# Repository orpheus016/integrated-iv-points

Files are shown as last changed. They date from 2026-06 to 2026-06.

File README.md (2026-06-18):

# four-point-probe
Four point probe for semiconductor instrumentation system

## Software: voltage simulation pipeline

This repo includes a modular Python simulation for voltage acquisition with
filters, live plotting, and CSV logging. It is designed to be swapped later with
ADS1256 serial input from Arduino.

## Development

If you plan to change code, start with:

- [CONTRIBUTING.md](CONTRIBUTING.md) for the CI contract, local preflight, and PR checklist.
- [software/scripts/README.md](software/scripts/README.md) for `evaluate`, `integrate`, and the compliance checker.
- [software/README.md](software/README.md) for the software module overview and run examples.
- `CONTRIBUTING.md` also explains how to write new tests under `software/tests/` and run them from the repo root.

### Setup

Install dependencies:

```bash
pip install matplotlib
```

Optional (for future ADS1256 serial input):

```bash
pip install pyserial
```

### Run

From the repo root:

```bash
python -m software.main
```

Example with custom settings:

```bash
python -m software.main --sample-rate 100 --window-seconds 8 --noise 0.0005 --step
```

## Offline data paths

There are two ways to work with recorded CSV data:

1. Replay a CSV through the live runtime when you want the same pipeline as hardware, including the backbone, logger, and visualizer:

```bash
python -m software.main --source csv --csv-path software/output/testbench/stable20mA.csv --backbone baseline
```

2. Run offline evaluation when you want metrics and snapshot comparison without hardware commands or the live plot loop:

```bash
python -m software.scripts.evaluate --input software/output/testbench/stable20mA.csv --backbones baseline --out software/output/evaluate/baseline-stable20mA
```

The offline evaluator writes a metrics CSV with the decided snapshot fields, marks that chosen snapshot with a star in the plot, and keeps the result separate from the live runtime output.

The default snapshot recording gate is configured in [software/config/config.py](software/config/config.py), including the minimum recording duration used before a backbone may decide on a VI snapshot.

## Serial protocol and CLI

Hardware integration uses a small text protocol implemented by the Arduino firmware and
managed by `software/command/serial_commander.py`.

Framing markers (exact strings):

- `*STREAM_START` — emitted by the Arduino to mark stream beginning
- `*STREAM_STOP` — emitted by the Arduino to mark stream termination

Control commands sent from host to Arduino (single ASCII characters):

- `R` — reset device
- `C` — start streaming samples
- `s` — stop streaming
- `iN` — set current stage to `N` (e.g. `i2`)

The serial reader expects CSV-style measurement lines containing `voltage,current_mA`.

Common CLI execution examples:

- Replay testbench CSVs and write evaluation results:
	python -m software.scripts.evaluate --input software/output/testbench --out results/

Single backbone on single dataset (example):
	python -m software.scripts.evaluate \
		--input software/output/testbench/stable20mA.csv \
		--backbones baseline \
		--out results/single_baseline_stable20mA
- Run main with hardware ADS1256 on COM5:
	python -m software.main --source serial --port COM5 --baud 115200 --backbone baseline
- Run headless evaluation from Python:
	python -c "from software.scripts.evaluate import main; main(['--input','software/output/testbench'])"

See `software/config/config.py` for all CLI defaults and flags (backbone selection, hysteresis thresholds, plot mode, etc.).

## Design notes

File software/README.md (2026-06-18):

Four-point probe voltage simulation and snapshot capture.

## What is this
This folder contains a modular Python simulation that mimics four-point probe voltage
measurements. It generates a true voltage from current and resistance, applies realistic
transient response and noise, and then detects when the signal stabilizes so it can
capture a frozen snapshot of the measurement.

## File overview
- `config/config.py`
   - CLI defaults and tunables for simulation, serial timing, switching policy, and output routing.
- `backbones/base.py`
   - Abstract streaming interface: `update(sample) -> Optional[Snapshot]`.
- `backbones/stddev_window.py`
   - Sliding-window stability detector with incremental variance.
- `backbones/running_stat.py`
   - Running-stat snapshot strategy with the same streaming backbone contract.
- `backbones/baseline.py`
   - Baseline snapshot strategy built on the sliding-window stddev rule.
- `backbones/hysteresis.py`
   - Hysteresis snapshot strategy with enter/exit thresholds and dwell.
- `command/serial_commander.py`
   - Serial protocol state engine for ADS1256 hardware control and stage switching.
- `data_source/ads1256.py`
   - Hardware streaming generator for Arduino/ADS1256.
- `data_source/dummy.py`
   - Synthetic signal generator for smoke tests and local development.
- `data_source/settling.py`
   - Synthetic settling sequence for backbone testing.
- `data_source/worst_case.py`
   - Synthetic worst-case data source for stability experiments.
- `data_source/manual_capture.py`
   - Manual data-capture entrypoint.
- `data_source/instrument_meas.py`
   - Reference hardware capture example kept for comparison.
- `utils/csv_replay.py`
   - CSV replay generator for `voltage,current_mA` datasets.
- `utils/backbone_factory.py`
   - Shared backbone selection helper used by `main.py`, `scripts/evaluate.py`, and `scripts/integrate.py`.
- `utils/filters.py`
   - Moving average and optional low-pass filtering.
- `utils/logger.py`
   - CSV logging for measured, true, and snapshot values.
- `utils/math.py`
   - Shared math helpers for rolling mean/std/RMS calculations.
- `utils/types.py`
   - Frozen `Snapshot` data contract and shared sample alias.
- `utils/visualization.py`
   - Live plot and async plot wrapper.
- `main.py`
   - Real-time orchestration only: data source -> backbone -> logger/visualizer.
- `scripts/evaluate.py`
   - Offline evaluation over testbench CSVs.
- `scripts/integrate.py`
   - Library-style entrypoints for downstream systems.
- `scripts/ci_compliance.py`
   - Lightweight architecture and cleanup checker used by CI.
- `scripts/backbone_workflow.py`
   - Fail-fast helper that scaffolds backbone registry updates and runs compliance.
- `scripts/README.md`
   - Developer guide for script entrypoints and command examples.
- `tests/test_evaluate.py`
   - Smoke test for offline evaluation.
- `tests/test_async_visualizer.py`
   - Headless visualization test.
- `tests/test_baseline.py` and `tests/test_hysteresis.py`
   - Backbone behavior tests.

## Run from repo root
Examples showing common runs. Use `--help` for full CLI options.

### Live plotting with `main`

`software.main` can show a live plot while acquisition is running. The key flags are:

- `--plot-mode full` shows the rolling live trace, current buffer, and snapshot line while samples stream in.
- `--plot-mode comparison` keeps the final comparison-style view.
- `--live-plot` enables the GUI plotter (omit or `--no-live-plot` to disable).
- `--plot-update-hz` throttles how often the plot updates (lower values reduce GUI overhead).
- `--save-plot-on-interrupt` saves the final comparison image on `Ctrl+C` when a snapshot exists.
- `--plot-backend` is optional (use only if you need to force a backend like `TkAgg` or `QtAgg`).
- `--live-backbones` runs multiple backbones on the same stream and shows a live transient comparison.
- `--live-duration` sets how long live multi-backbone capture runs (defaults to `--max-measurement`).

The plot opens in the same process as `main`, so keep the terminal running until you stop the stream or the snapshot completes.

1. One-shot measurement using the default `running_stat` strategy:
   python -m software.main --source dummy --backbone running_stat --current 0.01 --resistance 1.5 \
      --snapshot-threshold 0.0004 --snapshot-window 2.0 --snapshot-min-duration 2.0

   If you need gain correction in the stored resistance, add `--gain <value>`.

   Live plotting version of the same run:
   python -m software.main --source dummy --backbone running_stat \
      --current 0.01 --resistance 1.5 --snapshot-threshold 0.0004 \
      --snapshot-window 2.0 --snapshot-min-duration 2.0 --plot-mode full --live-plot

2. Hysteresis-based snapshot with explicit enter/exit thresholds:
   python -m software.main --source dummy --backbone hysteresis \
      --hysteresis-enter 0.020 --hysteresis-exit 0.015 --snapshot-window 1.0

3. Replay a CSV testbench dataset and log outputs to `software/output/testbench`:
   python -m software.main --source csv --csv-path software/output/testbench/stable20mA.csv \
      --backbone running_stat --stop-on-snapshot

   Live plotting while replaying the CSV:
   python -m software.main --source csv --csv-path software/output/testbench/stable20mALONG.csv \
      --backbone baseline --plot-mode full --stop-on-snapshot --live-plot

   Single backbone on a single dataset:
   python -m software.scripts.evaluate --input software/output/testbench/stable20mA.csv \
      --backbones running_stat --out software/output/evaluate/running_stat-stable20mA

   Batch evaluate the whole testbench folder:
   python -m software.scripts.evaluate --input software/output/testbench \
      --backbones running_stat,stddev_window,baseline,hysteresis --out software/output/evaluate/batch

4. Use the hardware ADS1256 input (COM port configured via `--port`):
   python -m software.main --source serial --port COM5 --baud 115200 --backbone baseline \
      --plot-mode full --live-plot --plot-update-hz 15

   If you want the stream to keep running after the first stable snapshot, disable auto-stop:
   python -m software.main --source serial --port COM5 --baud 115200 --backbone baseline \
      --plot-mode full --live-plot --no-stop-on-snapshot

   Save a final comparison image even on manual interrupt:
   python -m software.main --source serial --port COM5 --baud 115200 --backbone baseline \
      --plot-mode full --live-plot --save-plot-on-interrupt

   Live multi-backbone comparison for a fixed duration:
   python -m software.main --source serial --port COM5 --baud 115200 \
      --live-backbones baseline,stddev_window,hysteresis,running_stat --live-duration 20 \
      --plot-mode full --live-plot

Notes:
- Snapshot detection strategies live in `software/backbones/` and implement `update(sample) -> Optional[Snapshot]`.
- `running_stat.py` is the import-safe running-stat backbone implementation; the legacy hyphenated helper file was removed so CI only sees valid modules.
- Runtime parameters and CLI defaults are centralized in `software/config/config.py`.
- Outputs are routed into `software/output/<source>/<run_name>/` to keep hardware and testbench logs separate.
- For live acquisition, `--plot-mode full` is the most useful setting because it shows the running trace instead of only the end-state comparison.
- When a snapshot exists and the run ends, the final comparison image is saved next to the CSV as `*_final.png`.
- Serial runs also save a combined transient plot next to the CSV as `<csv_stem>_transient.png`.
- Serial current switching is snapshot-driven: switching only evaluates on stable snapshots (or a forced snapshot after `--switch-max-settle`). A blanking window (`--switch-blanking`) resets filters and backbones after a stage change before stability checks resume.
- Voltage-based raise thresholds use per-stage hysteresis bands (`--switch-raise-low` and `--switch-raise-high`), while power-limit downshifts apply at all stages (`--switch-power-limit-mw`).
- Stop-on-snapshot can be gated after a stage switch using `--stop-holdoff` (seconds), `--stop-require-post-switch`, and `--stop-final-holdoff` to avoid stopping on the same snapshot that triggers a switch, including on the final stage.
- The preferred developer workflow lives in [CONTRIBUTING.md](../CONTRIBUTING.md) and [scripts README](scripts/README.md).

## Snapshot function: where it is and how it works
The core snapshot behavior is implemented in main.py inside the main loop:
- Rolling buffer collects filtered voltages.
- A rolling stddev check decides when the signal is stable.
- When stable long enough, a snapshot voltage is captured and frozen.
- If stop-on-snapshot is enabled, the loop exits and a final comparison view is shown.

Key variables to look for in main.py:
- `MovingAverageFilter`
- `LowPassFilter`
- `create_backbone(...)`
- `mean_rms(...)`
- `backbone.update((timestamp, voltage, current_mA))`

## How to integrate snapshot into the larger FPP software
Use this as the reference pipeline:
1. Identify your measured voltage stream (raw or filtered).
2. Insert the same rolling/stability logic used by the selected backbone, not a second copy in the orchestration loop.
3. When stddev <= threshold for a minimum duration, compute a snapshot value.
4. Freeze the snapshot and stop acquisition if desired.
5. Display the snapshot next to the true/reference value.

Suggested integration steps:
1. Port the snapshot block from main.py into your acquisition loop.
2. Feed the block with filtered voltage for better stability.
3. Keep the parameters configurable:
    - snapshot_window_s
    - snapshot_std_threshold_v
    - snapshot_min_duration_s
4. Use stop-on-snapshot when you want a one-shot measurement.
5. For continuous monitoring, switch to snapshot-mode continuous.

## Common tuning tips
- If snapshot never triggers, increase snapshot threshold or enable low-pass filtering.
- If snapshot triggers too early, increase snapshot window or min duration.
- For noisy environments, use a lower low-pass alpha (e.g., 0.05 to 0.2).

## Capture Data

### Manual Capture

```bash
# Execute with default config settings (COM12, 115200 baud)
python -m software.data_source.manual_capture
# Override targets using the integrated arg_parser flags
python -m software.data_source.manual_capture --port COM5 --baud 115200 --filename step_response_test
```

You might want to use manual capture to test the VI capture algorithm on specific datasets, or to collect custom datasets for testing and development. Alternatively, you can use the algorithmic based data_source to generate synthetic data with specific characteristics (e.g. noise, transient response, line interference) to test the snapshot algorithm under controlled conditions.

Use the csv_replay generator to replay existing datasets in the same format as the ads1256 reader, which is what the snapshot algorithm is currently built and tested on.

### Auto Capture

You can use ads1256 capture for more automated data collection. this data_source is going to be integrated into the automated four point probe system measurement

## Offline evaluation (evaluate.py)

You can run the offline evaluator against either recorded CSVs or the built-in synthetic generators (`dummy`, `settling`, `worst_case`). The evaluator is useful for batch comparisons and produces a per-run PNG and a `*-metrics.csv` file with simple snapshot metrics and a marker for the decided snapshot.

Examples (run from the repo root):

- Dummy source (5 s at 50 Hz, compare two backbones):
- Dummy source (5 s at 50 Hz, compare the new running-stat backbone against the existing strategies):

```bash
python -m software.scripts.evaluate --source dummy \
   --max-measurement 5 --sample-rate 50 \
   --backbones running_stat,stddev_window,baseline \
   --out software/output/evaluate
```

- Settling source (3 s at 100 Hz, baseline only):

```bash
python -m software.scripts.evaluate --source settling \
   --max-measurement 3 --sample-rate 100 \
   --backbones baseline \
   --out software/output/evaluate
```

- Worst-case source (10 s, full compare):

```bash
python -m software.scripts.evaluate --source worst_case \
   --max-measurement 10 --sample-rate 50 \
   --backbones running_stat,stddev_window,baseline,hysteresis \
   --out software/output/evaluate
```

- Manual Capture
```bash
python -m software.scripts.evaluate --input software/output/testbench/stable20mALONG.csv --backbones baseline --out software/output/evaluate/baseline-stable20mALONG
```

- Transient playback with animation shown on screen only:
```bash
python -m software.scripts.evaluate --input software/output/testbench/stable20mALONG.csv \
   --backbones running_stat,baseline,stddev_window,hysteresis \
   --evaluation-plot-mode transient --evaluation-animate --evaluation-animation-output screen \
   --out software/output/evaluate/transient-demo
```

- Transient playback exported to GIF or video:
```bash
python -m software.scripts.evaluate --input software/output/testbench/stable20mALONG.csv \
   --backbones running_stat,baseline,stddev_window,hysteresis \
   --evaluation-plot-mode transient --evaluation-animate --evaluation-animation-output gif \
   --out software/output/evaluate/transient-gif
```

Key flags:
- `--source`: `csv`, `dummy`, `settling`, or `worst_case`.
- `--max-measurement`: maximum generator duration (seconds) for synthetic sources.
- `--sample-rate`: sample frequency used by synthetic generators.
- `--backbones`: comma-separated backbone names to run (e.g. `running_stat,baseline`).
- `--show`: display interactive plots (omit for CI/headless runs).
- `--evaluation-plot-mode`: `comparison` for IV plots or `transient` for time-based playback.
- `--evaluation-animate`: enable incremental playback in transient mode.
- `--evaluation-animation-output`: `screen`, `gif`, or `video` when animation is enabled.
- `--evaluation-animation-fps`: frame rate used for exported animation files.

Outputs created:
- `--out`/`<name>.png` — IV comparison plot, or transient plot when `--evaluation-plot-mode transient` is selected.
- `--out`/`<name>.gif` or `--out`/`<name>.mp4` — exported animation when the output mode is set accordingly.
- `--out`/`<name>-metrics.csv` — CSV summary with decided snapshot metadata and metrics (RMSE, MAE, MaxAbs).
- `software/scripts/backbone_workflow.py` can scaffold registry updates for a new backbone name, create a module stub if needed, and then run compliance plus tests.

Programmatic usage (call helpers directly):

```python
from software.config.config import build_arg_parser, build_simulation_config
from software.utils.evaluate_helpers import build_source_iterator_eval, evaluate_samples

args = build_arg_parser().parse_args(['--source','dummy','--max-measurement','2'])
sim = build_simulation_config(args)
samples = build_source_iterator_eval('dummy', sim, args)
data = evaluate_samples(samples, ['baseline'], sim, args)
```

Pointers:
- CLI defaults and all flags live in `software/config/config.py`.
- Reusable evaluation utilities are in `software/utils/evaluate_helpers.py`.
- Use `software/utils/backbone_factory.py` to construct backbones consistently across `main.py` and evaluation scripts.

### Output Folder Structure

output offline eval structure
```bash
output/evaluate/[data_source(.py/.csv)]/
|
-- transient-demo
|	|
|	-- [backbone name] (specific transient backbone)
|
-- [backbone name] (specific static backbone)
|
-- .png and.csv of all backbone
```

output/ads1256 for online evaluation with hardware

output/testbench for manual capture dataset from hardware

## CI Contract

TBA

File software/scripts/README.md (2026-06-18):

# Scripts Guide

This folder contains the repository's developer-facing entrypoints.

## `backbone_workflow.py`

Scaffold a new backbone, update the registry files, and run compliance.

Dry-run example:

```powershell
python software/scripts/backbone_workflow.py running_stat --dry-run
```

Apply changes and run compliance:

```powershell
python software/scripts/backbone_workflow.py running_stat
```

The helper updates `software/config/config.py`, `software/utils/backbone_factory.py`, and `software/backbones/__init__.py`, then runs `software/scripts/ci_compliance.py`. If a matching `software/tests/test_<name>.py` file exists, it runs that test file too.

## `evaluate.py`

Offline evaluation over CSV testbench data.

Typical single-dataset, single-backbone run:

```powershell
python -m software.scripts.evaluate --input software/output/testbench/stable20mA.csv --backbones baseline --out software/output/evaluate/baseline-stable20mA
```

Batch run over the full testbench folder:

```powershell
python -m software.scripts.evaluate --input software/output/testbench --backbones stddev_window,baseline,hysteresis --out software/output/evaluate/batch
```

The script reads CSV replay data from `software/utils/csv_replay.py`, runs each backbone in isolation, and writes PNG and CSV summary outputs.

If your measurements need gain correction, pass `--gain <value>` so the evaluator and `software.main` use the same resistance formula.

Note: `evaluate.py` also supports the built-in synthetic sources (`dummy`, `settling`, `worst_case`) and uses reusable helpers in `software/utils/evaluate_helpers.py`. Backbone construction is delegated to `software/utils/backbone_factory.py`.

For transient behavior analysis, use `--evaluation-plot-mode transient`. You can leave animation screen-only with `--evaluation-animation-output screen`, or export it with `--evaluation-animation-output gif` or `--evaluation-animation-output video`.

Example transient run with multiple backbones:

```powershell
python -m software.scripts.evaluate --input software/output/testbench/stable20mALONG.csv --backbones running_stat,baseline,stddev_window,hysteresis --evaluation-plot-mode transient --evaluation-animate --evaluation-animation-output screen --out software/output/evaluate/transient-demo
```

## `integrate.py`

Programmatic API for downstream use.

Example imports:

```python
from software.scripts.integrate import create_backbone, create_commander, run_pipeline
```

Use `create_backbone(...)` when you need a repository-consistent backbone factory, `create_commander(...)` when you need hardware control, and `run_pipeline(...)` for a small streaming loop that writes snapshots through `CsvLogger`.

## `ci_compliance.py`

Lightweight architecture check used by CI.

Run it directly:

```powershell
python software/scripts/ci_compliance.py
```

The checker validates the current repository shape against `copilot-instructions.md`, including `Snapshot`, backbone inheritance, CSV replay imports, duplicate helper cleanup, and the `add_argument` location rule.

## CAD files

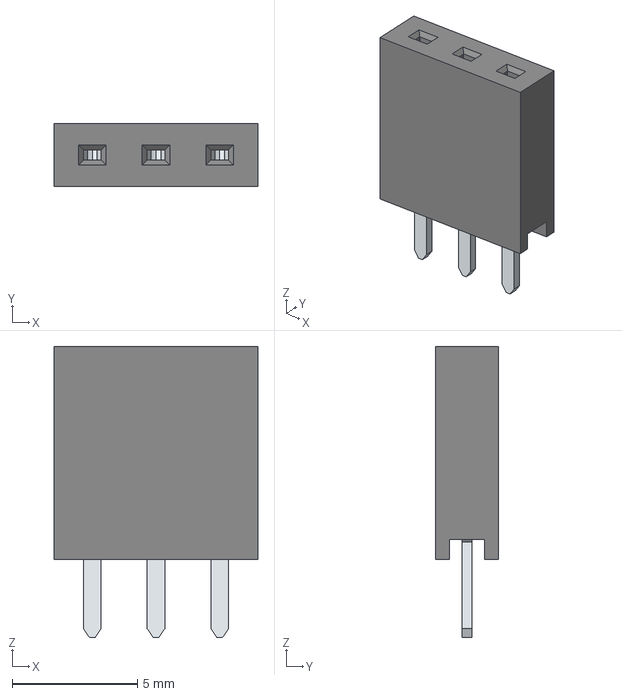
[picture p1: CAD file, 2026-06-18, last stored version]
hardware/PCB/Custom Parts/6130XX11821_61300311821/6130XX11821_61300311821.step
8.12 x 2.50 x 11.6 mm

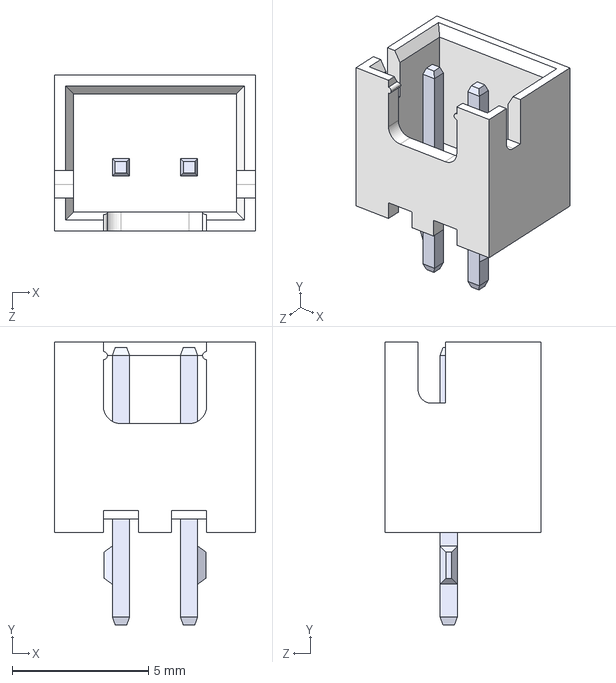
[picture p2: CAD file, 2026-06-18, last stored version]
hardware/PCB/Custom Parts/B2B-XH-A/B2B-XH-A.step
7.40 x 10.4 x 5.75 mm

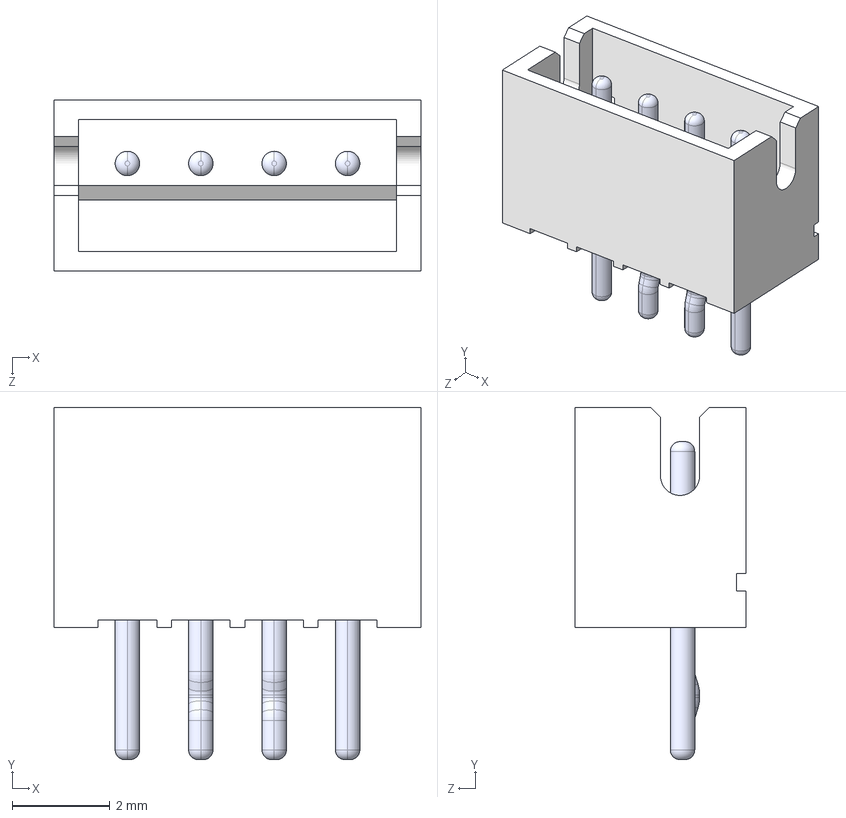
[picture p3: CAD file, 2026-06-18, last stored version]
hardware/PCB/Custom Parts/B4B-ZR/B4B-ZR.step
7.50 x 7.20 x 3.50 mm
BxB-ZR_4
pin_straight x 2
pin_Bent x 2

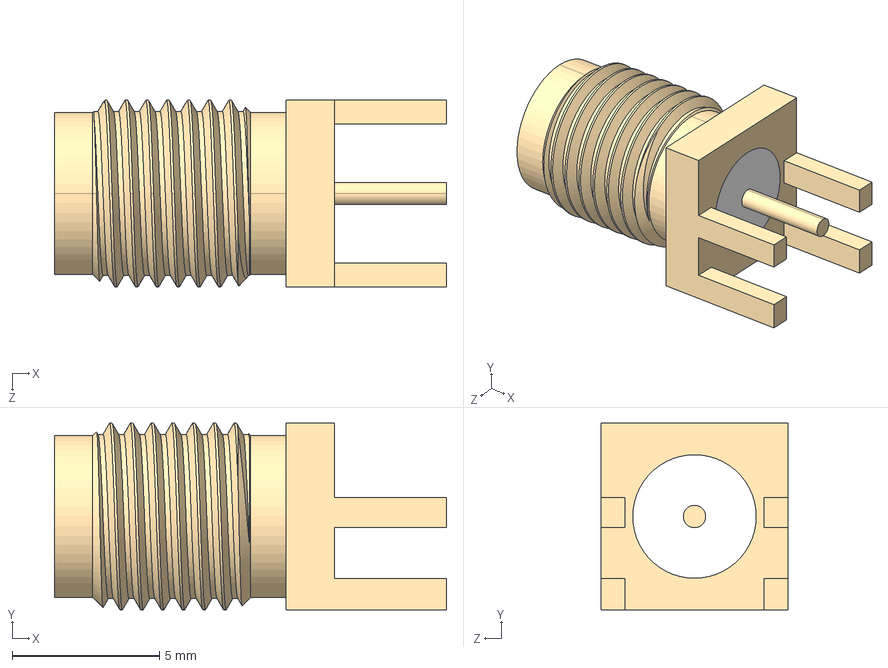
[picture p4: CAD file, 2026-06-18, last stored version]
hardware/PCB/Custom Parts/CON-SMA-EDGE-S/CON-SMA-EDGE-S--3DModel-STEP-269445.STEP
13.3 x 6.35 x 6.35 mm

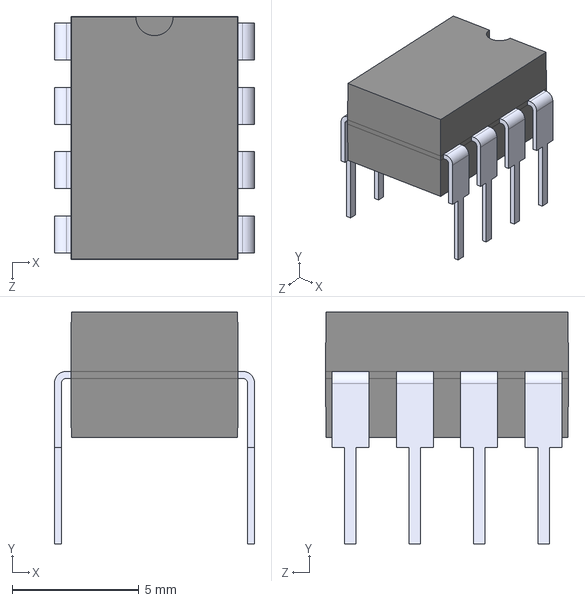
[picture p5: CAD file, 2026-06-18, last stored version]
hardware/PCB/Custom Parts/ICL7660SCPAZ/ICL7660SCPAZ.step
7.90 x 9.14 x 9.59 mm

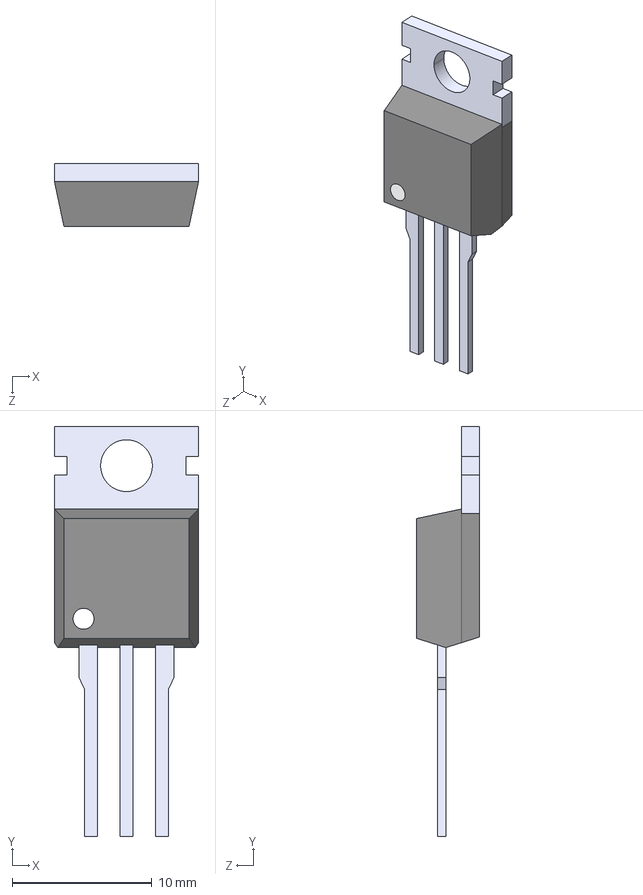
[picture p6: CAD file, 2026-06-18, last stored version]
hardware/PCB/Custom Parts/IRFZ44N/IRFZ44N.step
10.3 x 29.3 x 4.50 mm

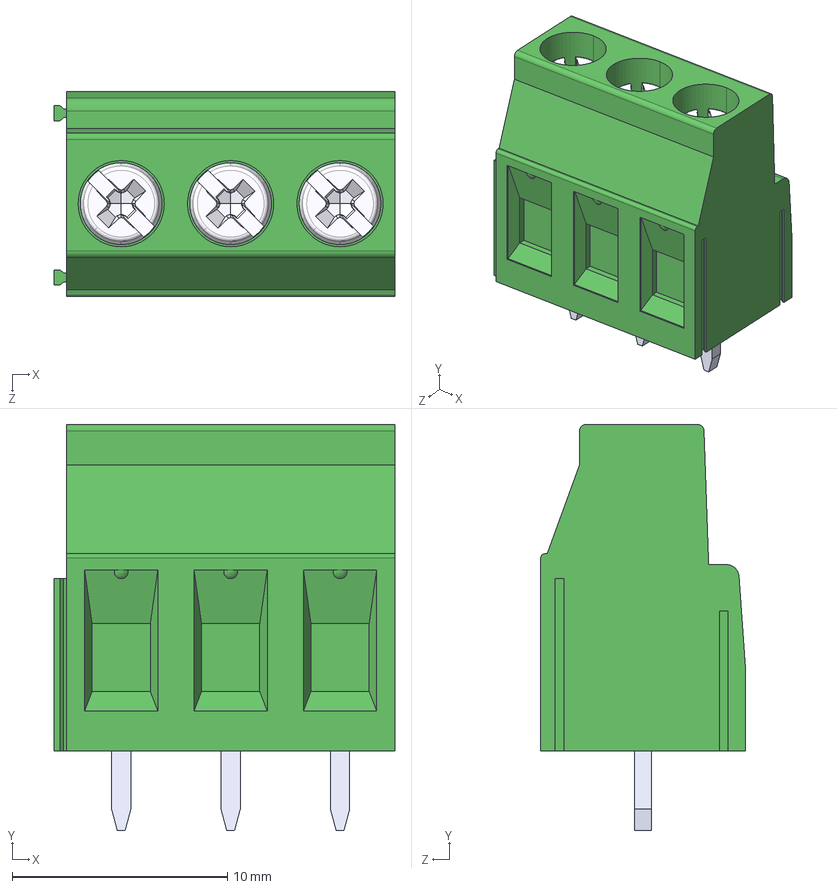
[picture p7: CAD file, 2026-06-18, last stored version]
hardware/PCB/Custom Parts/MKDSN2_5_3-5.08/MKDSN2_5_3-5.08.step
15.8 x 18.9 x 9.50 mm

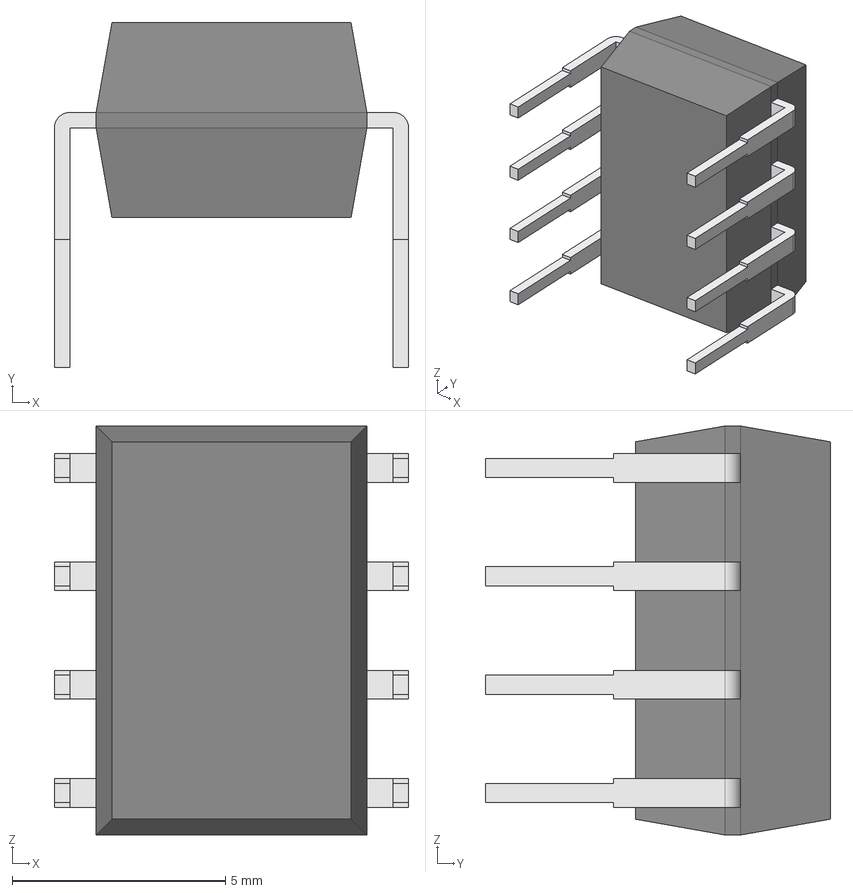
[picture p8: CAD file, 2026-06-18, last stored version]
hardware/PCB/Custom Parts/OP07CP/OP07CP.step
8.31 x 8.08 x 9.59 mm
Body001 (Mirror #1) x 5

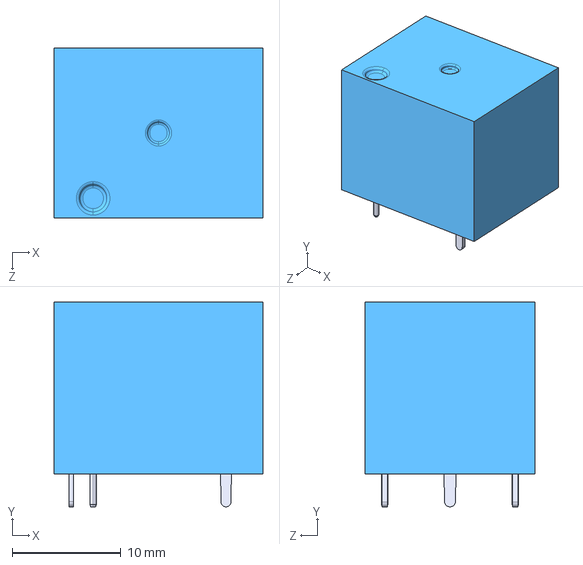
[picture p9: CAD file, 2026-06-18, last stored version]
hardware/PCB/Custom Parts/SRD-12VDC-SL-C/SRD-12VDC-SL-C.step
19.2 x 18.8 x 15.6 mm

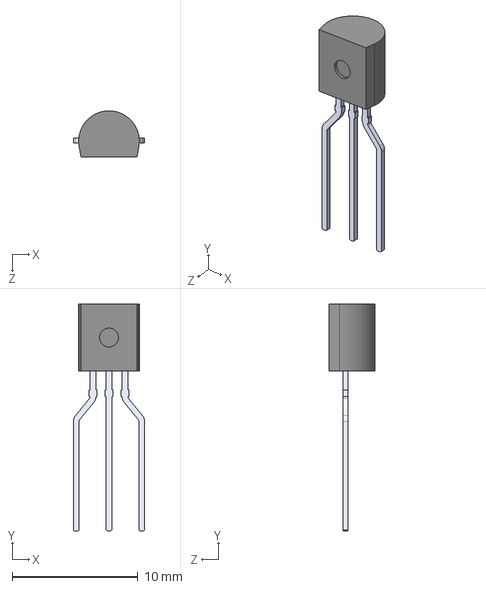
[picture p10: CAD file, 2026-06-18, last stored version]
hardware/PCB/Custom Parts/TL431ACLP/TL431ACLP.step
5.67 x 18.0 x 3.68 mm

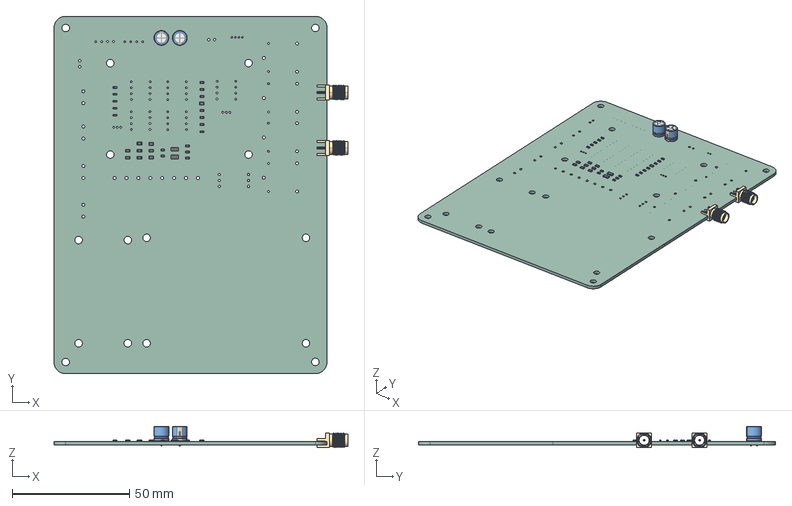
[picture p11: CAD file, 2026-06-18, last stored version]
hardware/PCB/InstrumentV3/Print Instrumentasi/.step
125.4 x 152.5 x 9.10 mm
R_0603_1608Metric x 17
R_0805_2012Metric x 9
CP_Radial_D6.3mm_P2.50mm x 2
R_1206_3216Metric x 2
CON-SMA-EDGE-S_CON-SMA-EDGE-S x 2
InstrumentV3_PCB

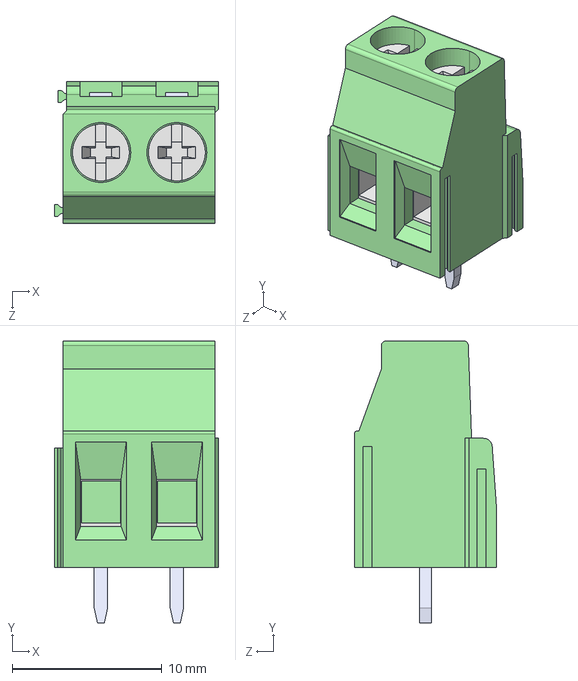
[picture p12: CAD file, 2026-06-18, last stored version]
hardware/PCB/Custom Parts/1888687/1888687.step
11.0 x 18.9 x 9.50 mm

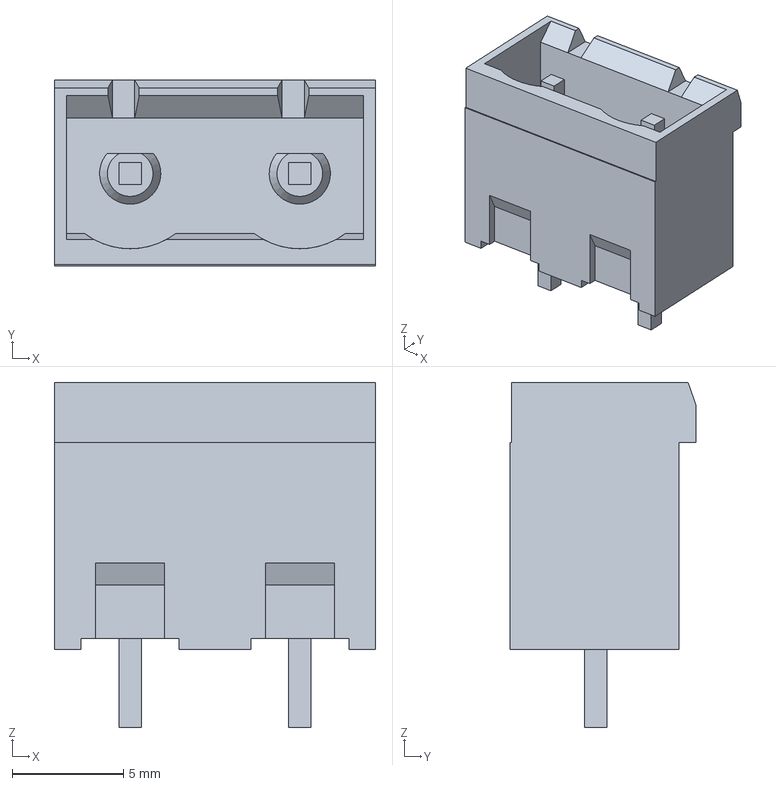
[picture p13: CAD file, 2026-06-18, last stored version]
hardware/PCB/Custom Parts/796980-2/796980-2.step
14.4 x 8.35 x 15.5 mm

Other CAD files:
hardware/PCB/Custom Parts/CON-SMA-EDGE-S/CON-SMA-EDGE-S.step

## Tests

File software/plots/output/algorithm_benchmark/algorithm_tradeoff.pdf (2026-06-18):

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

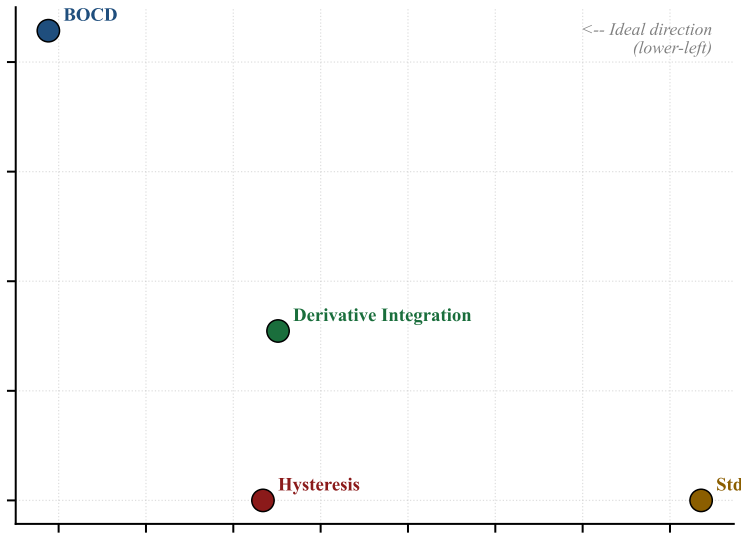
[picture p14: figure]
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

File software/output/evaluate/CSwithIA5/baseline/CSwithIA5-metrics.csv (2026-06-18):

backbone | decided_snapshot | decided_timestamp | decided_voltage | decided_current_mA | decided_resistance | decided_std_dev | decided_stage | rmse | mae | maxabs | num_snapshots
baseline | * | 1.960000 | 0.03631364 | 4.00000000 | 4.49426255 | 0.00002409 |  | 1.3877787807814457e-17 | 1.3877787807814457e-17 | 1.3877787807814457e-17 | 1

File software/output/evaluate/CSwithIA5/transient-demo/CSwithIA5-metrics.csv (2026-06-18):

backbone | decided_snapshot | decided_timestamp | decided_voltage | decided_current_mA | decided_resistance | decided_std_dev | decided_stage | rmse | mae | maxabs | num_snapshots
baseline | * | 1.960000 | 0.03631364 | 4.00000000 | 4.49426255 | 0.00002409 |  | 1.3877787807814457e-17 | 1.3877787807814457e-17 | 1.3877787807814457e-17 | 1
stddev_window | * | 1.960000 | 0.03631364 | 4.00000000 | 4.49426255 | 0.00002409 |  | 1.3877787807814457e-17 | 1.3877787807814457e-17 | 1.3877787807814457e-17 | 1
hysteresis | * | 8.680000 | 0.03627241 | 4.00000000 | 4.48915965 |  |  | 2.022620000000086e-05 | 2.022620000000086e-05 | 2.022620000000086e-05 | 0
running_stat | * | 1.960000 | 0.03631364 | 4.00000000 | 4.49426255 | 0.00002409 |  | 1.3877787807814457e-17 | 1.3877787807814457e-17 | 1.3877787807814457e-17 | 1

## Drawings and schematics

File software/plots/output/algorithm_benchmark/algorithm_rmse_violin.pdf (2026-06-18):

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

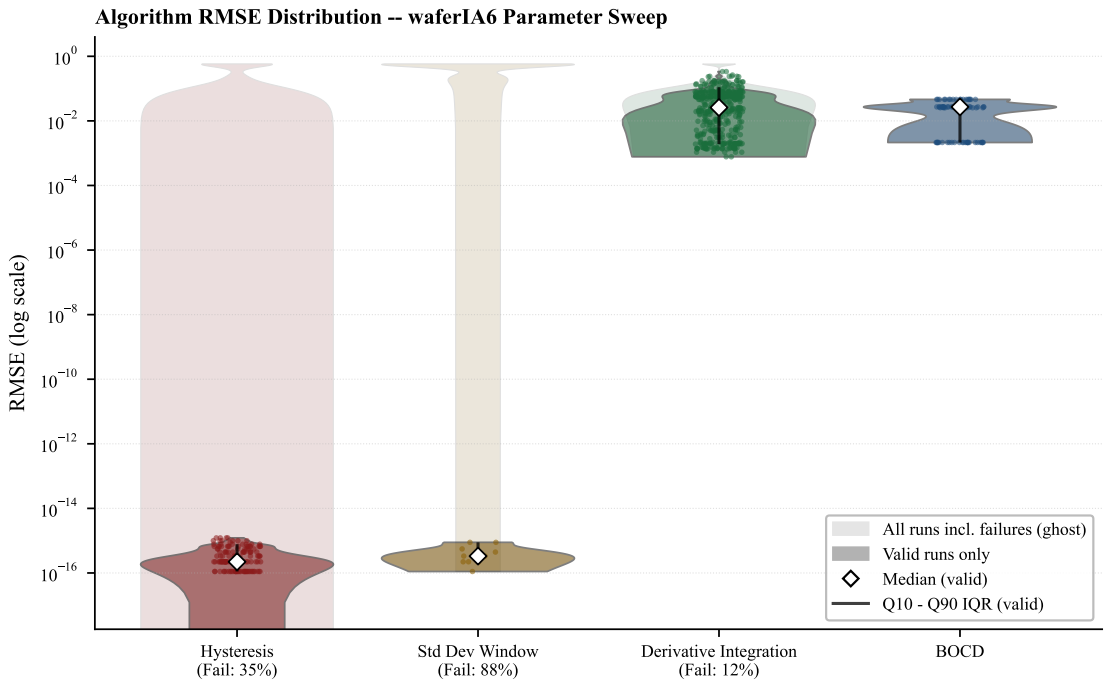
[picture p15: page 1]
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

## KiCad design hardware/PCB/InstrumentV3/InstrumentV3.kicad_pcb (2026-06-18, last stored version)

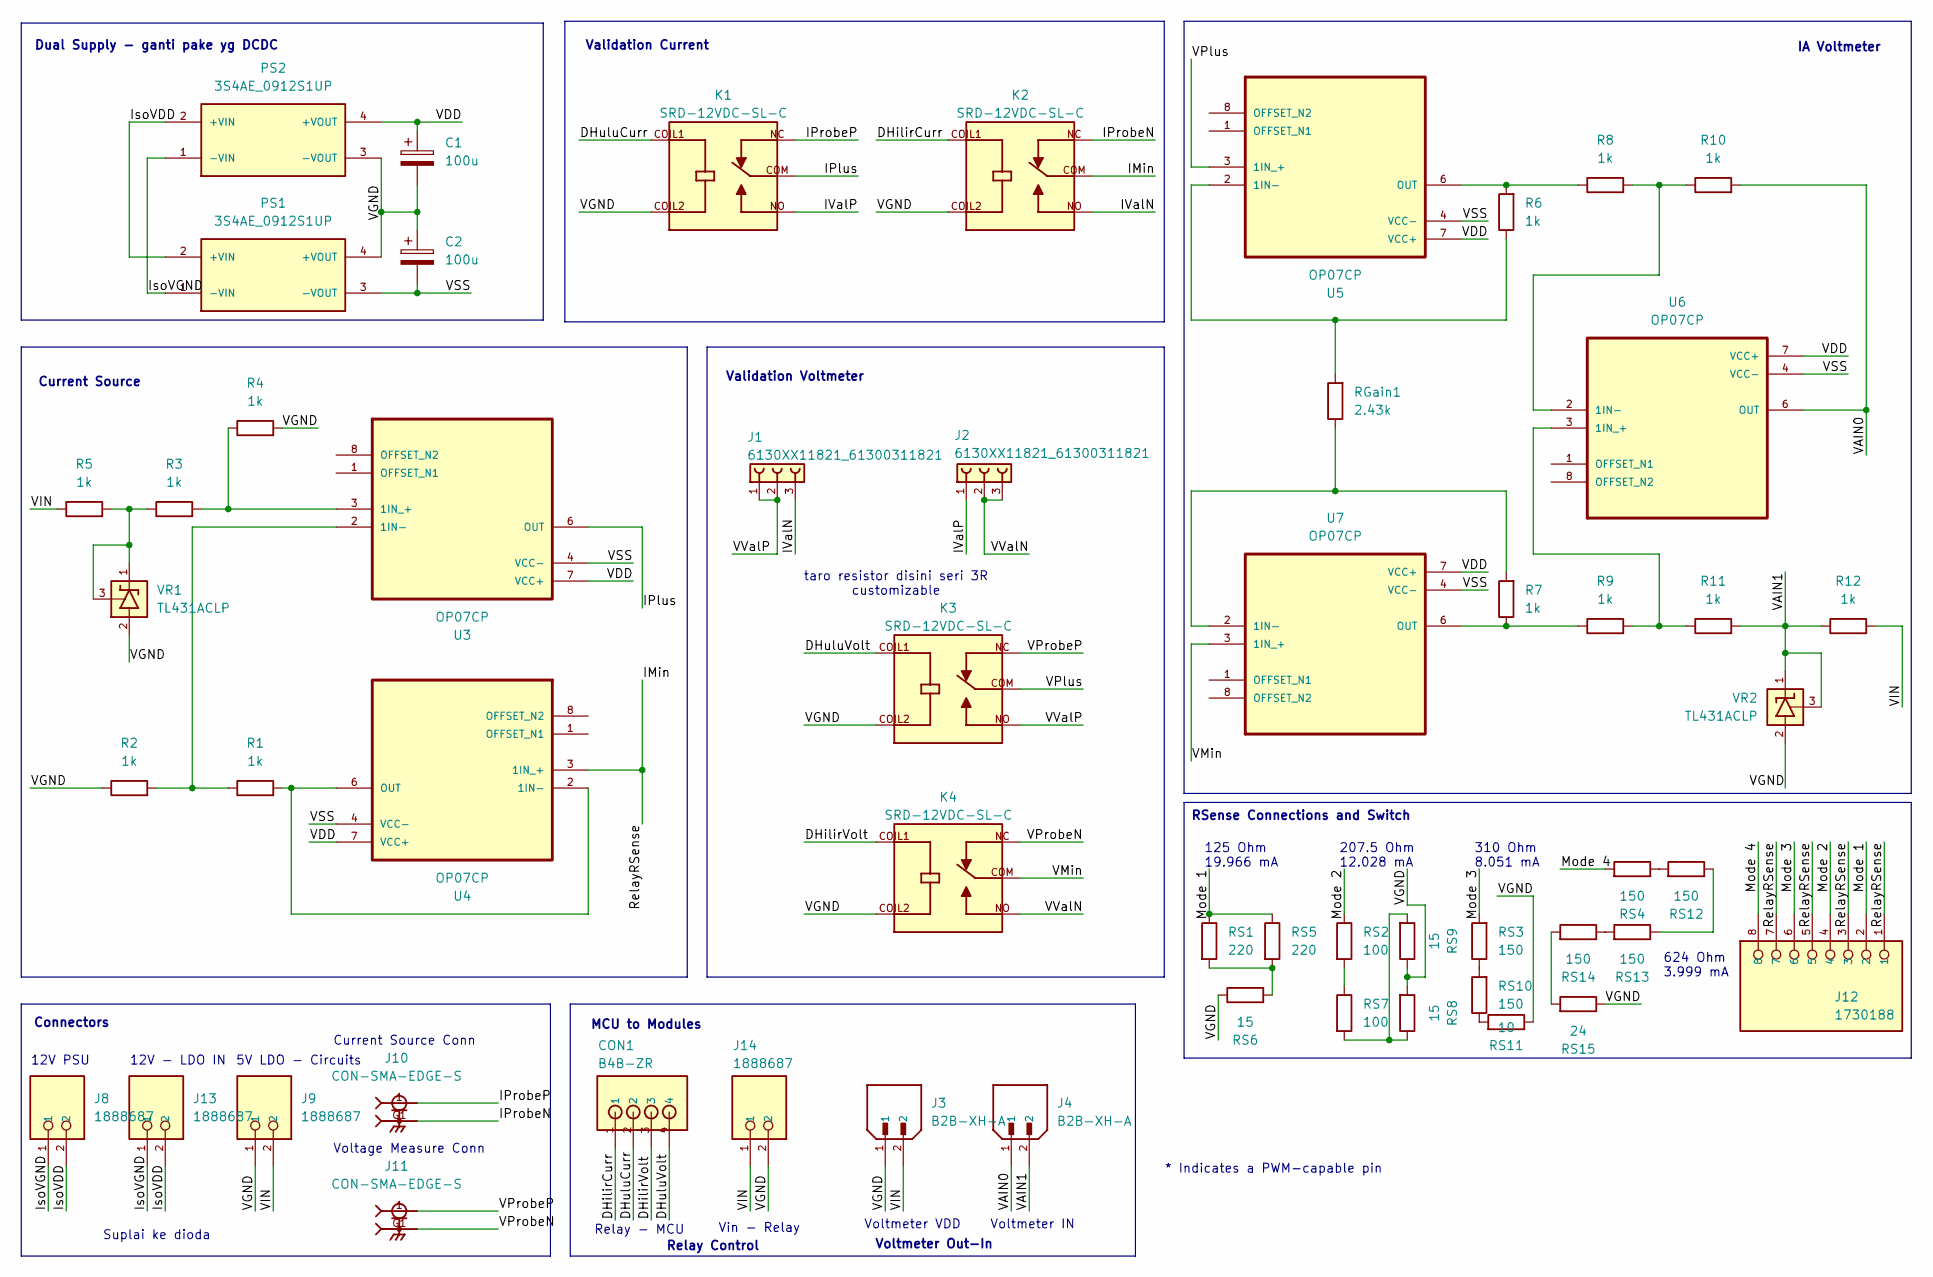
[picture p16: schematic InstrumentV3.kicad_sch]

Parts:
C1, C2: 100u; CP_Radial_D6.3mm_P2.50mm
CON1: B4B-ZR
J1, J2: 6130XX11821_61300311821; 61300311821
J3, J4: B2B-XH-A; JST_B2B-XH-A; PARTREV N/A
J8, J9, J13, J14: 1888687; PHOENIX_1888687; PARTREV 26.09.2015
J10, J11: CON-SMA-EDGE-S; RFSOLUTIONS_CON-SMA-EDGE-S; PARTREV 1
J12: 1730188; PHOENIX_1730188
K1, K2, K3, K4: SRD-12VDC-SL-C; RELAY_SRD-12VDC-SL-C; PARTREV 1.0
PS1, PS2: 3S4AE_0912S1UP; CONV_3S4AE_0912S1UP; PARTREV 2019-1.0
R1, R2, R3, R4, R5, R6, R7, R8, R9, R10, R11, R12: 1k; R_0603_1608Metric_Pad0.98x0.95mm_HandSolder
RGain1: 2.43k; R_0805_2012Metric_Pad1.20x1.40mm_HandSolder
RS1, RS5: 220; R_0603_1608Metric_Pad0.98x0.95mm_HandSolder
RS2, RS7: 100; R_1206_3216Metric_Pad1.30x1.75mm_HandSolder
RS3, RS4, RS10, RS12, RS13, RS14: 150; R_0805_2012Metric_Pad1.20x1.40mm_HandSolder
RS6, RS8, RS9: 15; R_0603_1608Metric_Pad0.98x0.95mm_HandSolder
RS11: 10; R_0805_2012Metric_Pad1.20x1.40mm_HandSolder
RS15: 24; R_0805_2012Metric_Pad1.20x1.40mm_HandSolder
U3, U4, U5, U6, U7: OP07CP; DIP794W45P254L959H508Q8
VR1, VR2: TL431ACLP; VREG_TL431ACLP; PARTREV R

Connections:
/DHilirCurr: CON1.1, K2.COIL1
/DHilirVolt: CON1.3, K4.COIL1
/DHuluCurr: CON1.2, K1.COIL1
/DHuluVolt: CON1.4, K3.COIL1
/IMin: J12.1, J12.3, J12.5, J12.7, K2.COM, U4.3 (1IN_+)
/IPlus: K1.COM, U3.6 (OUT)
/IProbeN: J10.G1, J10.G2, J10.G3, J10.G4, K2.NC
/IProbeP: J10.1, K1.NC
/IValN: J1.3, K2.NO
/IValP: J2.1, K1.NO
/IsoVDD: J8.2, J13.2, PS1.2 (+VIN), PS2.2 (+VIN)
/IsoVGND: J8.1, J13.1, PS1.1 (-VIN), PS2.1 (-VIN)
/Mode 1: J12.2, RS1.1, RS5.1
/Mode 2: J12.4, RS2.1
/Mode 3: J12.6, RS3.2
/Mode 4: J12.8, RS4.2
/VAIN0: J4.1, R10.2, U6.6 (OUT)
/VAIN1: J4.2, R11.2, R12.1, VR2.1, VR2.3
/VDD: C1.1, PS2.4 (+VOUT), U3.7 (VCC+), U4.7 (VCC+), U5.7 (VCC+), U6.7 (VCC+), U7.7 (VCC+)
/VGND: C1.2, C2.1, J3.1, J9.1, J14.2, K1.COIL2, K2.COIL2, K3.COIL2, K4.COIL2, PS1.4 (+VOUT), PS2.3 (-VOUT), R2.1, R4.2, RS6.1, RS8.2, RS9.1, RS11.1, RS15.1, VR1.2, VR2.2
/VIN: J3.2, J9.2, J14.1, R5.1, R12.2
/VMin: K4.COM, U7.3 (1IN_+)
/VPlus: K3.COM, U5.3 (1IN_+)
/VProbeN: J11.G1, J11.G2, J11.G3, J11.G4, K4.NC
/VProbeP: J11.1, K3.NC
/VSS: C2.2, PS1.3 (-VOUT), U3.4 (VCC-), U4.4 (VCC-), U5.4 (VCC-), U6.4 (VCC-), U7.4 (VCC-)
/VValN: J2.2, J2.3, K4.NO
/VValP: J1.1, J1.2, K3.NO
unnamed: R3.1, R5.2, VR1.1, VR1.3
unnamed: RS1.2, RS5.2, RS6.2
unnamed: RS2.2, RS7.1
unnamed: RS7.2, RS8.1, RS9.2
unnamed: RS10.1, RS11.2
unnamed: RS3.1, RS10.2
unnamed: RS12.1, RS13.1
unnamed: RS4.1, RS12.2
unnamed: RS13.2, RS14.1
unnamed: RS14.2, RS15.2
unnamed: R1.1, R2.2, U3.2 (1IN-)
unnamed: R3.2, R4.1, U3.3 (1IN_+)
unnamed: R1.2, U4.2 (1IN-), U4.6 (OUT)
unnamed: R6.1, RGain1.2, U5.2 (1IN-)
unnamed: R6.2, R8.1, U5.6 (OUT)
unnamed: R8.2, R10.1, U6.2 (1IN-)
unnamed: R9.2, R11.1, U6.3 (1IN_+)
unnamed: R7.2, RGain1.1, U7.2 (1IN-)
unnamed: R7.1, R9.1, U7.6 (OUT)

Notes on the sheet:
624 Ohm 3.999 mA
Voltmeter Out-In
Voltmeter VDD
Relay Control
Connectors
Suplai ke dioda
IA Voltmeter
5V LDO - Circuits
Validation Voltmeter
Validation Current
taro resistor disini seri 3R customizable
310 Ohm 8.051 mA
12V - LDO IN
Current Source Conn
12V PSU
Dual Supply - ganti pake yg DCDC
Current Source
125 Ohm 19.966 mA
Relay - MCU
* Indicates a PWM-capable pin
Voltage Measure Conn
207.5 Ohm 12.028 mA
Vin - Relay
Voltmeter IN
RSense Connections and Switch
MCU to Modules

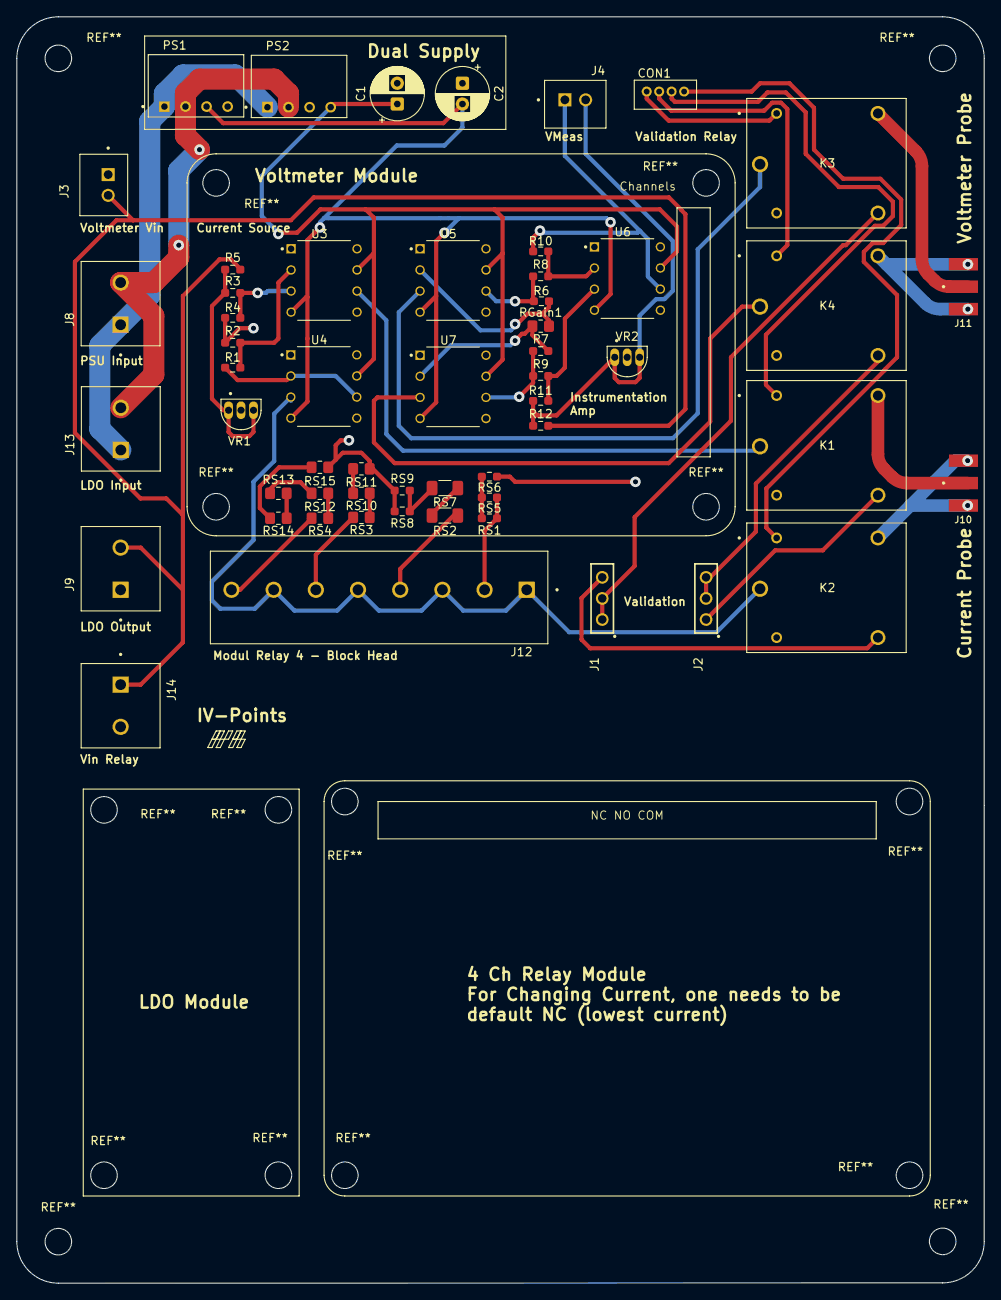
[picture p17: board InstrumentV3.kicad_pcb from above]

Board: 2 copper layers, 116.5 x 152.5 mm, 55 parts (0 on the bottom side), 47 nets.

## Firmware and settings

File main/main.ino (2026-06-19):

// =====================================================
// MAIN FILE (.ino)
// =====================================================

#include "XYControl.h"
#include "ZControl.h"
#include "temperature.h"
#include "instrument.h"

#define FAN 42
#define VRX_PIN A1
#define VRY_PIN A0
#define SW_PIN 43

volatile bool singlePointMode = false;

unsigned long lastTempUpdate = 0;
const unsigned long tempInterval = 2000;

// =====================================================
// JOYSTICK DIAMETER LIMIT
// =====================================================
float joystickDiameter = 0.0;
float joystickRadius = 0.0;

// =====================================================
// GLOBAL FLAGS
// =====================================================
volatile bool emergencyStop = false;
volatile bool isHoming = false;

// =====================================================
// FUNCTION PROTOTYPES
// =====================================================
bool checkEmergencyEnd();
void handleEmergencyReset();
void runJoystickMode();
void setupInstrument();

bool insideCircle(long targetXSteps, long targetYSteps);

// =====================================================
// CHECK FOR END COMMAND
// =====================================================
bool checkEmergencyEnd() {

  if (Serial.available() > 0) {

    String cmd = Serial.readStringUntil('\n');
    cmd.trim();

    if (cmd.equalsIgnoreCase("END")) {

      emergencyStop = true;

      return true;
    }
  }

  return emergencyStop;
}

// =====================================================
// HANDLE EMERGENCY RESET
// =====================================================
void handleEmergencyReset() {

  isHoming = true;

  digitalWrite(VAC, LOW);

  // =============================================
  // SINGLE POINT
  // only home Z
  // =============================================
  if (singlePointMode) {

    homeZ();
  }

  // =============================================
  // MULTI POINT / MANUAL
  // normal full home
  // =============================================
  else {

    homeZ();
    homeXY();
  }

  emergencyStop = false;
  isHoming = false;

  singlePointMode = false;
}

// =====================================================
// CHECK IF POSITION IS INSIDE CIRCLE
// =====================================================
bool insideCircle(long targetXSteps, long targetYSteps) {

  // convert steps -> cm
  float xCm = (targetXSteps / stepsPerCm) / 2.0;
  float yCm = (targetYSteps / stepsPerCm) / 2.0;

  float distanceSquared = (xCm * xCm) + (yCm * yCm);
  float radiusSquared = joystickRadius * joystickRadius;

  return distanceSquared <= radiusSquared;
}

// =====================================================
// SETUP
// =====================================================
void setup() {

  Serial.begin(115200);

  Serial.setTimeout(50);

  initTemperatureSensors();
  //printMLX();
  pinMode(FAN, OUTPUT);

  digitalWrite(FAN, LOW);
  delay(1000);
  digitalWrite(FAN, HIGH);

  pinMode(SW_PIN, INPUT_PULLUP);
  setupInstrument();


  setupXY();
  setupZ();

  homeZ();
  homeXY();

  //printMLX();
}

// =====================================================
// MAIN LOOP
// =====================================================
void loop() {

  // =============================================
  // HANDLE EMERGENCY
  // =============================================
  if (emergencyStop) {

    handleEmergencyReset();
    return;
  }

  // =============================================
  // TEMPERATURE UPDATE
  // =============================================
  /*
  if (millis() - lastTempUpdate >= tempInterval) {

    printSHT();

    lastTempUpdate = millis();
  }
  */

  // =============================================
  // SERIAL COMMANDS
  // =============================================
  if (Serial.available() > 0) {

    String input = Serial.readStringUntil('\n');
    input.trim();

    // =========================================
    // MANUAL MODE
    // =========================================
    if (input.startsWith("m")) {

      int spaceIndex = input.indexOf(' ');

      // default = unlimited movement
      joystickDiameter = 0;
      joystickRadius = 0;

      // example:
      // m 10.16
      if (spaceIndex > 0) {

        joystickDiameter = input.substring(spaceIndex + 1).toFloat();

        if (joystickDiameter > 0) {

          joystickRadius = joystickDiameter / 2.0;
        }
      }

      runJoystickMode();
    }

    // =========================================
    // AUTO MODES
    // =========================================
    else {

      int spaceIndex = input.indexOf(' ');

      if (spaceIndex > 0) {

        int mode = input.substring(0, spaceIndex).toInt();
        float diameter = input.substring(spaceIndex + 1).toFloat();

        if (diameter <= 0) return;

        // =====================================
        // MODE 1
        // =====================================
        if (mode == 1) {

          runSequence1(diameter);
        }

        // =====================================
        // MODE 5
        // =====================================
        else if (mode == 5) {

          runSequence5(diameter);
        }

        // =====================================
        // MODE 9
        // =====================================
        else if (mode == 9) {

          runSequence9(diameter);
        }
      }
    }
  }
}

// =====================================================
// JOYSTICK MODE
// =====================================================
void runJoystickMode() {

  bool active = true;

  digitalWrite(VAC, HIGH);

  while (active) {

    // =========================================
    // EMERGENCY CHECK
    // =========================================
    if (checkEmergencyEnd()) {

      active = false;
      break;
    }

    // =========================================
    // READ JOYSTICK
    // =========================================
    int xVal = analogRead(VRX_PIN);
    int yVal = analogRead(VRY_PIN);

    // =========================================
    // X AXIS
    // =========================================
    if (xVal < 300 && digitalRead(X_MIN) == HIGH) {

      long nextX = currentX - 1;

      if (joystickRadius <= 0 || insideCircle(nextX, currentY)) {

        moveStep(STEP_X, DIR_X, LOW);
        currentX--;
      }
    }

    else if (xVal > 700 && digitalRead(X_MAX) == HIGH) {

      long nextX = currentX + 1;

      if (joystickRadius <= 0 || insideCircle(nextX, currentY)) {

        moveStep(STEP_X, DIR_X, HIGH);
        currentX++;
      }
    }

    // =========================================
    // Y AXIS
    // =========================================
    if (yVal < 300 && digitalRead(Y_MIN) == HIGH) {

      long nextY = currentY - 1;

      if (joystickRadius <= 0 || insideCircle(currentX, nextY)) {

        moveStep(STEP_Y, DIR_Y, LOW);
        currentY--;
      }
    }

    else if (yVal > 700 && digitalRead(Y_MAX) == HIGH) {

      long nextY = currentY + 1;

      if (joystickRadius <= 0 || insideCircle(currentX, nextY)) {

        moveStep(STEP_Y, DIR_Y, HIGH);
        currentY++;
      }
    }

    // =========================================
    // PROBE BUTTON
    // =========================================
    if (digitalRead(SW_PIN) == LOW) {

      delay(200);

      Serial.println("Confirm");

      bool waitingForConfirm = true;

      while (waitingForConfirm) {

        // =====================================
        // ONLY CHECK FLAG
        // =====================================
        if (emergencyStop) {

          active = false;
          waitingForConfirm = false;
          break;
        }

        // =====================================
        // SERIAL RESPONSE
        // =====================================
        if (Serial.available() > 0) {

          String response = Serial.readStringUntil('\n');
          response.trim();

          // =================================
          // END
          // =================================
          if (response.equalsIgnoreCase("END")) {

            emergencyStop = true;

            active = false;
            waitingForConfirm = false;

            break;
          }

          // =================================
          // YES
          // =================================
          else if (response.equalsIgnoreCase("Y")) {

            zProbe(false);

            waitingForConfirm = false;
          }

          // =================================
          // NO
          // =================================
          else if (response.equalsIgnoreCase("N")) {

            waitingForConfirm = false;
          }
        }
      }

      // =========================================
      // WAIT RELEASE
      // =========================================
      while (digitalRead(SW_PIN) == LOW) {

        if (emergencyStop) {

          active = false;
          break;
        }
      }
    }

    // =========================================
    // POSITION PRINT
    // =========================================
    if (millis() - lastPrintMove >= printIntervalMove) {

      lastPrintMove = millis();

      Serial.print("X: ");
      Serial.println(-(currentX / stepsPerCm) / 2);

      Serial.print("Y: ");
      Serial.println(-(currentY / stepsPerCm) / 2);
    }

    delayMicroseconds(stepDelay);
  }

  digitalWrite(VAC, LOW);
}

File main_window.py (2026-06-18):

# main_window.py
from PySide6.QtWidgets import QMainWindow, QStackedWidget

from pages.home_page import HomePage
from pages.loading_page import LoadingPage
from pages.result_page import ResultPage
from pages.historical_data_page import HistoricalDataPage
from measurement import DEFAULT_TEMP_C, run_measurement, calculate_doping


class MainWindow(QMainWindow):
    def __init__(self):
        super().__init__()
        self.setWindowTitle("Four Point Probe Interface")
        self.setMinimumSize(1000, 700)

        self.stack = QStackedWidget()
        self.setCentralWidget(self.stack)

        self.home = HomePage()
        self.loading = LoadingPage()
        self.result = ResultPage()
        self.historical = HistoricalDataPage()

        self.stack.addWidget(self.home)
        self.stack.addWidget(self.loading)
        self.stack.addWidget(self.result)
        self.stack.addWidget(self.historical)

        self.home.start_measurement.connect(self._show_loading)
        self.loading.loading_complete.connect(self._loading_finished)
        self.result.back_to_home.connect(self._go_home)
        self.home.view_historical_data.connect(self._show_historical)
        self.historical.back_to_home.connect(self._go_home)

        # Store measurement parameters
        self._thickness = None
        self._carrier = None
        self._wafer_area = None
        self._diameter = None
        self._wafer_area_cm2 = None
        self._x_cm = 0.0
        self._y_cm = 0.0
        self._num_points = 1
        self._measurement_points = []
        self._temperature_c = DEFAULT_TEMP_C

    def _show_loading(self, thickness, carrier, wafer_area, diameter, wafer_area_cm2, x_cm, y_cm, num_points=1, temperature_c=DEFAULT_TEMP_C, mode=""):
        """Store measurement parameters and show loading screen."""
        self._thickness = thickness
        self._carrier = carrier
        self._wafer_area = wafer_area
        self._diameter = diameter
        self._wafer_area_cm2 = wafer_area_cm2
        self._x_cm = x_cm
        self._y_cm = y_cm
        self._num_points = num_points
        self._temperature_c = float(temperature_c)
        self._measurement_points = []

        self.result.reset_results()
        
        # Configure loading page
        self.loading.set_num_points(num_points)
        self.loading.set_wafer_params(diameter, wafer_area_cm2, carrier, thickness, carrier, self._temperature_c)
        
        # Connect home page serial reader to loading page for real-time measurement collection
        if hasattr(self.home, '_serial_reader') and self.home._serial_reader is not None:
            try:
                self.home._serial_reader.position_received.disconnect(self.loading.on_position_received)
            except:
                pass
            self.home._serial_reader.position_received.connect(self.loading.on_position_received)
            try:
                self.home._serial_reader.temperature_received.disconnect(self.loading.on_temperature_received)
            except:
                pass
            self.home._serial_reader.temperature_received.connect(self.loading.on_temperature_received)
            try:
                self.home._serial_reader.confirm_received.disconnect(self.loading.on_confirm_received)
            except:
                pass
            self.home._serial_reader.confirm_received.connect(self.loading.on_confirm_received)
            try:
                self.home._serial_reader.measurement_started.disconnect(self.loading.on_measurement_started)
            except:
                pass
            self.home._serial_reader.measurement_started.connect(self.loading.on_measurement_started)
            try:
                self.home._serial_reader.voltage_received.disconnect(self.loading.on_voltage_received)
            except:
                pass
            self.home._serial_reader.voltage_received.connect(self.loading.on_voltage_received)
            try:
                self.home._serial_reader.current_received.disconnect(self.loading.on_current_received)
            except:
                pass
            self.home._serial_reader.current_received.connect(self.loading.on_current_received)
            try:
                self.home._serial_reader.measurement_stopped.disconnect(self.loading.on_measurement_stopped)
            except:
                pass
            self.home._serial_reader.measurement_stopped.connect(self.loading.on_measurement_stopped)
            # Also connect MLX sensor readings (wafer measurement temperature) if available
            try:
                try:
                    self.home._serial_reader.mlx_temperature_received.disconnect(self.loading.on_temperature_received)
                except:
                    pass
                # MLX readings should be handled by loading.on_mlx_temperature_received
                try:
                    self.home._serial_reader.mlx_temperature_received.connect(self.loading.on_mlx_temperature_received)
                except Exception:
                    # Fallback: connect to generic handler if specific handler missing
                    self.home._serial_reader.mlx_temperature_received.connect(self.loading.on_temperature_received)
            except Exception:
                # Older SerialReader instances may not have MLX signal; ignore
                pass
            # Pass serial reader and manual-mode flag to loading page
            try:
                self.loading.set_serial_reader(self.home._serial_reader)
            except Exception:
                pass
            try:
                self.loading.set_manual_mode(mode == "Manual Measurement")
            except Exception:
                pass
        
        self.stack.setCurrentWidget(self.loading)
        self.loading.start_loading(num_points)
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

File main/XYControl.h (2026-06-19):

// =====================================================
// XYControl.h
// =====================================================

#ifndef XY_CONTROL_H
#define XY_CONTROL_H

#define EN_XY 25

#define STEP_X 15
#define DIR_X 17

#define STEP_Y 23
#define DIR_Y 19

#define X_MIN 3
#define X_MAX 5

#define Y_MIN 2
#define Y_MAX 4

#define VAC 39

const float stepsPerCm = 2000.0;
const int stepDelay = 600;

extern volatile bool singlePointMode;

// =====================================================
// SHARED VARIABLES
// =====================================================
long currentX = 0;
long currentY = 0;

unsigned long lastPrintMove = 0;
const int printIntervalMove = 200;

bool cekHome = false;

// =====================================================
// EXTERNAL FLAGS
// =====================================================
extern volatile bool emergencyStop;
extern volatile bool isHoming;

// =====================================================
// FUNCTION DECLARATIONS
// =====================================================
void setupXY();
void homeXY();

void runSequence1(float d);
void runSequence5(float d);
void runSequence9(float d);

void runPoints(float pts[][2], int count);

void moveTo(float xCm, float yCm);

void moveStep(int stepPin,
              int dirPin,
              int dir);

void zProbe(bool fullReturn);

bool checkEmergencyEnd();

// =====================================================
// SETUP
// =====================================================
void setupXY() {

  pinMode(EN_XY, OUTPUT);

  pinMode(STEP_X, OUTPUT);
  pinMode(DIR_X, OUTPUT);

  pinMode(STEP_Y, OUTPUT);
  pinMode(DIR_Y, OUTPUT);

  pinMode(VAC, OUTPUT);

  pinMode(X_MIN, INPUT_PULLUP);
  pinMode(X_MAX, INPUT_PULLUP);

  pinMode(Y_MIN, INPUT_PULLUP);
  pinMode(Y_MAX, INPUT_PULLUP);

  digitalWrite(EN_XY, LOW);

  digitalWrite(VAC, LOW);
}

// =====================================================
// HOME XY
// =====================================================
void homeXY() {

  while (digitalRead(X_MIN) == HIGH ||
         digitalRead(Y_MIN) == HIGH) {

    // stop only if NOT currently homing
    if (emergencyStop && !isHoming) return;

    if (digitalRead(X_MIN) == HIGH) {

      moveStep(STEP_X, DIR_X, LOW);
    }

    if (digitalRead(Y_MIN) == HIGH) {

      moveStep(STEP_Y, DIR_Y, LOW);
    }

    delayMicroseconds(stepDelay + 200);
  }

  currentX = 0;
  currentY = 0;

  cekHome = true;

  moveTo(7.5, 7.675);

  cekHome = false;

  currentX = 0;
  currentY = 0;

  Serial.println(currentX);
  Serial.println(currentY);
}

// =====================================================
// MODE 1
// =====================================================
void runSequence1(float d) {

  float pts[1][2] = {
    {0,0}
  };

  singlePointMode = true;
  runPoints(pts, 1);
  if (!emergencyStop){
  singlePointMode = false;
  }
  Serial.println("0");
  Serial.println("0");
}

// =====================================================
// MODE 5
// =====================================================
void runSequence5(float d) {

  float R = d;

  float pts[5][2] = {

    {0,0},

    {(2.0/3.0)*R,0},

    {0,-(2.0/3.0)*R},

    {-(2.0/3.0)*R,0},

    {0,(2.0/3.0)*R}
  };

  runPoints(pts, 5);
}

// =====================================================
// MODE 9
// =====================================================
void runSequence9(float d) {

  float R = d;

  float pts[9][2] = {

    {0,0},

    {(2.0/3.0)*R,0},

    {0.47*R,-0.47*R},

    {0,-(2.0/3.0)*R},

    {-0.47*R,-0.47*R},

    {-(2.0/3.0)*R,0},

    {-0.47*R,0.47*R},

    {0,(2.0/3.0)*R},

    {0.47*R,0.47*R}
  };

  runPoints(pts, 9);
}

// =====================================================
// RUN POINTS
// =====================================================
void runPoints(float pts[][2], int count) {

  digitalWrite(VAC, HIGH);

  for (int i = 0; i < count; i++) {

    if (emergencyStop && !isHoming) return;

    // =========================================
    // SHOW TARGET POINT
    // =========================================
    //Serial.print("TARGET X: ");
    //Serial.println(pts[i][0], 3);

    //Serial.print("TARGET Y: ");
    //Serial.println(pts[i][1], 3);

    // =========================================
    // MOVE
    // =========================================
    moveTo(pts[i][0], pts[i][1]);

    Serial.println(-(currentX / stepsPerCm) /2);

    Serial.println(-(currentY / stepsPerCm) /2);

    if (emergencyStop && !isHoming) return;

    zProbe(i == count - 1);
  }

  digitalWrite(VAC, LOW);

  if (count != 1) {

    homeXY();
  }
}

// =====================================================
// MOVE TO
// =====================================================
void moveTo(float xCm, float yCm) { //xCm & yCm = koordinat tujuan

  long tx = xCm * stepsPerCm;
  long ty = yCm * stepsPerCm;

  long dx = tx - currentX;
  long dy = ty - currentY;

  long steps = max(abs(dx), abs(dy));

  if (steps == 0) return;

  float xInc = dx / (float)steps;
  float yInc = dy / (float)steps;

  float xAcc = currentX;
  float yAcc = currentY;

  for (long i = 0; i < steps; i++) {

    // stop only outside homing
    if (checkEmergencyEnd() && !isHoming) return;

    xAcc += xInc;
    yAcc += yInc;

    long nX = round(xAcc);
    long nY = round(yAcc);

    // =============================================
    // X
    // =============================================
    if (nX != currentX) {

      if (nX > currentX &&
          digitalRead(X_MAX) == HIGH) {

        moveStep(STEP_X, DIR_X, HIGH);
        currentX++;
      }

      else if (nX < currentX &&
               digitalRead(X_MIN) == HIGH) {

        moveStep(STEP_X, DIR_X, LOW);
        currentX--;
      }
    }

    // =============================================
    // Y
    // =============================================
    if (nY != currentY) {

      if (nY > currentY &&
          digitalRead(Y_MAX) == HIGH) {

        moveStep(STEP_Y, DIR_Y, HIGH);
        currentY++;
      }

      else if (nY < currentY &&
               digitalRead(Y_MIN) == HIGH) {

        moveStep(STEP_Y, DIR_Y, LOW);
        currentY--;
      }
    }

    // =============================================
    // POSITION PRINT
    // =============================================
    if (millis() - lastPrintMove >= printIntervalMove) {

      lastPrintMove = millis();

      float xOut = -(currentX / stepsPerCm)/2;
      float yOut = -(currentY / stepsPerCm)/2;

      if (!cekHome) {

        Serial.println(xOut);
        Serial.println(yOut);
      }
    }

    delayMicroseconds(stepDelay);
  }
}

// =====================================================
// SINGLE STEP
// =====================================================
void moveStep(int stepPin,
              int dirPin,
              int dir) {

  digitalWrite(dirPin, dir);

  digitalWrite(stepPin, HIGH);
  delayMicroseconds(10);
  digitalWrite(stepPin, LOW);
}

#endif

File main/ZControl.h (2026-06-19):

#ifndef Z_CONTROL_H
#define Z_CONTROL_H

#define EN_Z 31
#define STEP_Z 29
#define DIR_Z 27

#define Z_MIN 35
#define Z_MAX 37

// =====================================================
// EXTERNAL FLAGS
// =====================================================
extern volatile bool emergencyStop;
extern volatile bool isHoming;

// =====================================================
// FUNCTION DECLARATIONS
// =====================================================
bool checkEmergencyEnd();

void printMLX();
void streamContinuous_CSV(int posCh = 0, int negCh = 1);
void setupInstrument();

unsigned long temp0 = 0;
const unsigned long temp1 = 2000;

// =====================================================
// SETUP Z
// =====================================================
void setupZ() {

  pinMode(EN_Z, OUTPUT);

  pinMode(STEP_Z, OUTPUT);
  pinMode(DIR_Z, OUTPUT);

  pinMode(Z_MIN, INPUT_PULLUP);
  pinMode(Z_MAX, INPUT_PULLUP);

  digitalWrite(EN_Z, LOW);
}

// =====================================================
// SINGLE STEP
// =====================================================
void stepZ(int dly) {

  digitalWrite(STEP_Z, HIGH);
  delayMicroseconds(dly);

  digitalWrite(STEP_Z, LOW);
  delayMicroseconds(dly);
}

// =====================================================
// MOVE Z
// =====================================================
void moveZ(int steps, int dly) {

  for (int i = 0; i < steps; i++) {

    // =============================================
    // STOP ONLY IF NOT HOMING
    // =============================================
    if (checkEmergencyEnd() && !isHoming) return;

    // =============================================
    // LIMIT CHECKS
    // =============================================
    if (digitalRead(DIR_Z) == HIGH &&
        digitalRead(Z_MIN) == LOW) return;

    if (digitalRead(DIR_Z) == LOW &&
        digitalRead(Z_MAX) == LOW) return;

    stepZ(dly);
  }
}

// =====================================================
// HOME Z
// =====================================================
void homeZ() {

  digitalWrite(EN_Z, LOW);

  // =============================================
  // MOVE UP TO Z_MAX
  // =============================================
  digitalWrite(DIR_Z, LOW);

  while (digitalRead(Z_MAX) == HIGH) {

    // allow homing during emergency reset
    if (checkEmergencyEnd() && !isHoming) return;

    stepZ(600);
  }

  // =============================================
  // BACK OFF
  // =============================================
  digitalWrite(DIR_Z, HIGH);

  moveZ(400, 600);

  digitalWrite(EN_Z, HIGH);

}

// =====================================================
// Z PROBE
// =====================================================
void zProbe(bool fullReturn) {

  digitalWrite(EN_Z, LOW);

  // =============================================
  // GO DOWN
  // =============================================
  digitalWrite(DIR_Z, HIGH);

  if (checkEmergencyEnd() && !isHoming) return;

  // =============================================
  // FAST APPROACH
  // =============================================
  for (int i = 0; i < 4; i++) {

    if (digitalRead(Z_MIN) == LOW) break;

    if (checkEmergencyEnd() && !isHoming) return;

    moveZ(2000, 600);
  }

  // =============================================
  // SLOW APPROACH
  // =============================================
  while (digitalRead(Z_MIN) == HIGH) {

    if (checkEmergencyEnd() && !isHoming) return;

    moveZ(4, 1000);
  }

  // =============================================
  // TEMPERATURE
  // =============================================
  printMLX();
  Serial.println("STARTSTREAM");
  streamContinuous_CSV();

  //delay(2000);

  // =============================================
  // RETURN
  // =============================================
  if (fullReturn) {

    digitalWrite(VAC, LOW);

    // move upward to home
    digitalWrite(DIR_Z, LOW);

    while (digitalRead(Z_MAX) == HIGH) {

      if (checkEmergencyEnd() && !isHoming) return;

      stepZ(600);
    }

    // back off
    digitalWrite(DIR_Z, HIGH);

    moveZ(400, 600);
  }

  else {

    // partial lift
    digitalWrite(DIR_Z, LOW);

    moveZ(3000, 600);
  }

  digitalWrite(EN_Z, HIGH);
}

#endif

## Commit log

2026-06-19 add: integration
    [.step, 1888687.step, 6130XX11821_61300311821.step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]
2026-06-19 fix: integration
    [volt_log_20260619_145039.csv]
2026-06-19 fix: loading page frontend bridge
    [loading_page.py]
2026-06-19 fix: backend integration
    [volt_log_20260619_191114_638637.csv, volt_log_20260619_195345_255124.csv]
2026-06-19 add: output log
    [volt_log_20260619_145039.csv, volt_log_20260619_202223_572948.csv, volt_log_20260619_202316_373826.csv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]
2026-06-19 test: voltage gain on loading and result page
2026-06-19 test: current switching
2026-06-20 output: current switching
    [volt_log_20260620_160640_605759.csv, volt_log_20260620_163845_474296.csv]
2026-06-20 test: sample rate
2026-06-20 add: log
    [volt_log_20260620_192157_764388.csv, volt_log_20260620_195527_932185.csv, volt_log_20260620_195638_511187.csv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]
2026-06-21 test: reset to 4mA
    [volt_log_20260620_163845_474296.csv]
2026-06-21 test: vi snapshot from backend
    [volt_log_20260621_134502_675786.csv, volt_log_20260621_134539_623482.csv, volt_log_20260621_134609_545272.csv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]
2026-06-21 add: lod
    [volt_log_20260621_165908_979460.csv, volt_log_20260621_165957_679851.csv, volt_log_20260621_170136_930062.csv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]
